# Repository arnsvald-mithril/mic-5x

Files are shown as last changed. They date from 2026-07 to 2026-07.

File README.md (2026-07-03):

# MIC-5X — Indoor Microclimate Monitor

**MITHRIL ELECTRONICS** · Doc. MTH-DS-0001 · Datasheet Rev. C.1

A 5-parameter indoor microclimate monitor built on a bare ESP8266 (ESP-12F)
module with a custom-designed analog dust-sensing front-end — not a
pre-built sensor module, but a discrete nephelometric channel (IR LED +
photodiode + LM358 transimpedance amplifier) designed, simulated, and
laid out from scratch.

Board render
*(replace with actual board photo/render)*

## Measured parameters

| Parameter | Sensor  | Interface |
|---|---|---|
| Temperature | DHT22 | Digital (1-Wire-like) |
| Relative humidity | DHT22 | Digital |
| Barometric pressure | BMP280  | I2C |
| Illuminance | BH1750  | I2C |
| Particulate matter (dust) | Custom analog nephelometric channel | ADC (ESP8266 TOUT) |

Full electrical characteristics, error budget, and mechanical drawings:
see `datasheet/MIC-5X_Datasheet_RevC1.pdf`.

## Engineering highlights

- **Analog front-end design.** Custom TIA stage (LM358) for the dust
  channel, simulated in LTspice: DC transfer characteristic
  0.3-3.3 V at 0-30 uA photocurrent, two-pole filter (tau ~= 1.8 ms,
  -3 dB at ~90 Hz). See `hardware/simulation/`.
- **Full error budget.** Aggregated RSS error ~5-7%, dominated by LED
  thermal drift (~4-6%), with contributions from Vref/AMS1117 (~1.5%),
  R3 tempco (~0.3%), and LM358 bias current (~0.5%).
- **Bare-module hardware design.** Migrated from a NodeMCU dev board
  to a bare ESP-12F module with full boot-strapping (EN/RST/GPIO0/GPIO2
  pull-ups, GPIO15 pull-down), a complete power protection chain
  (PolyFuse -> Schottky -> TVS -> AMS1117), and ADC input protection
  for the dust channel.
- **DRC-clean 2-layer PCB** in KiCad, including ground pour with
  stitching vias.
- **Non-blocking firmware.** ~300-line Arduino sketch using millis()
  scheduling (no delay()), with sensor cross-validation (DHT22 vs
  BMP280 temperature check), pressure trend detection, and a fallback
  AP mode for field configuration.
- **3D-printed enclosure**, parametrically modeled in CadQuery, with
  snap-fit assembly (no screws) and a dedicated cross-flow air path
  for the dust sensor.

## Repository structure

```
mic-5x/
    hardware/
        schematic/     KiCad schematic + PDF export
        pcb/            KiCad PCB layout
        simulation/     LTspice results (TIA transfer & frequency response)
    firmware/           ESP8266 Arduino firmware
    enclosure/           CadQuery enclosure script + STEP/STL exports
    datasheet/           Full Rev. C.1 datasheet (PDF)
    docs/images/         Board photos, renders, simulation plots
```

## Known limitations

This is an honest engineering datasheet, not a marketing sheet —
current known issues:

- Dust channel is **not yet calibrated on real aerosol**; the
  0.3-3.3 V range is the simulated full-scale transfer characteristic,
  not a validated ppm/ug*m^-3 curve.
- Enclosure snap-fit tongues are sized for **PLA** specifically
  (~0.9% strain after redesign); other materials would need
  re-verification of engagement geometry.
- LTspice .asc source files were iterated in a single working draft
  and not preserved as separate versions — simulation plots are
  archived in docs/images/, and the circuit is fully reproducible
  from the parameters listed in the datasheet.
- Enclosure errata (S6.6 of the datasheet) documents six issues found
  during design review and their fixes (exhaust port, fan bore
  clearance, snap-fit strain, screw sizing, stray light path).

## License

MIT — see LICENSE.

## Author

Oleksandr Didyk — Bachelor of Electronics, Igor Sikorsky Kyiv
Polytechnic Institute, Faculty of Electronics, specialization in
Electronic Devices and Systems.

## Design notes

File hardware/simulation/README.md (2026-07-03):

\# LTspice simulations

Two key simulations validate the analog dust-sensing front-end (TIA stage):

1. \*\*Transfer characteristic\*\* — DC sweep 0–30 µA photocurrent →

0\.3–3.3 V output. Confirms the TIA gain stage operating range

used in the error budget (see datasheet §5.4).

TIA transfer

1. \*\*Frequency response\*\* — two-pole filter, τ ≈ 1.8 ms,

−3 dB at ~90 Hz.

TIA frequency response

Original `.asc` files were iterated directly and not preserved as

separate versions. Circuit parameters (Rf, Cf, LM358 config, BPW34

model) are fully specified in the datasheet and can be rebuilt from

those values if needed.

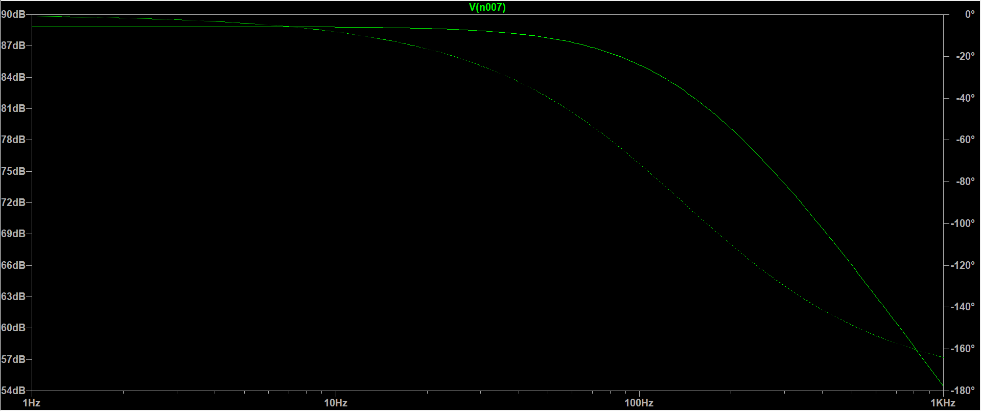
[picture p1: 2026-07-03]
docs/images/TIA_frequency_response.png

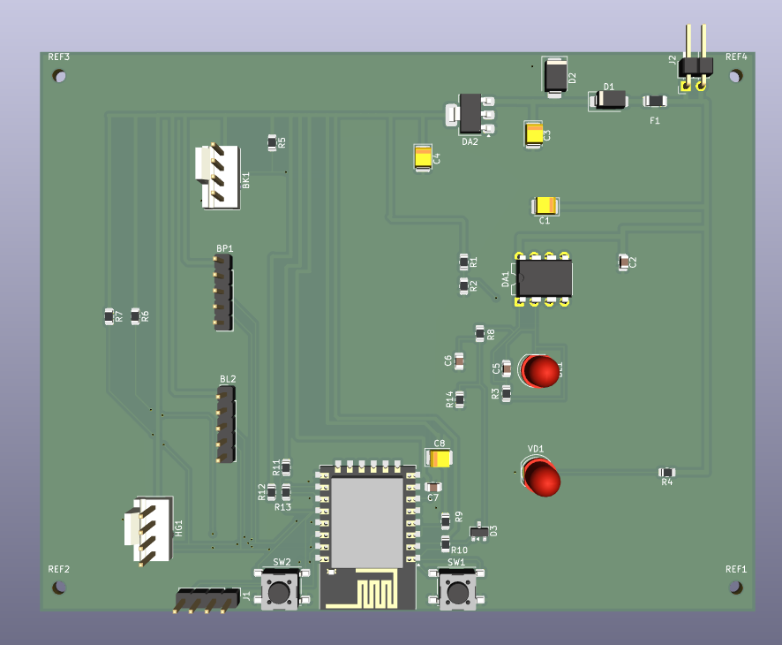
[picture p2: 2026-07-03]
docs/images/3D_model.png

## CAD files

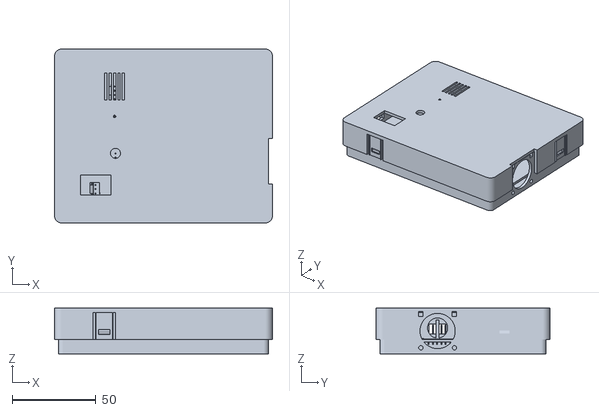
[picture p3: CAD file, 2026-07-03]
enclosure/exports/Assembly.stl
130.0 x 103.6 x 27.2

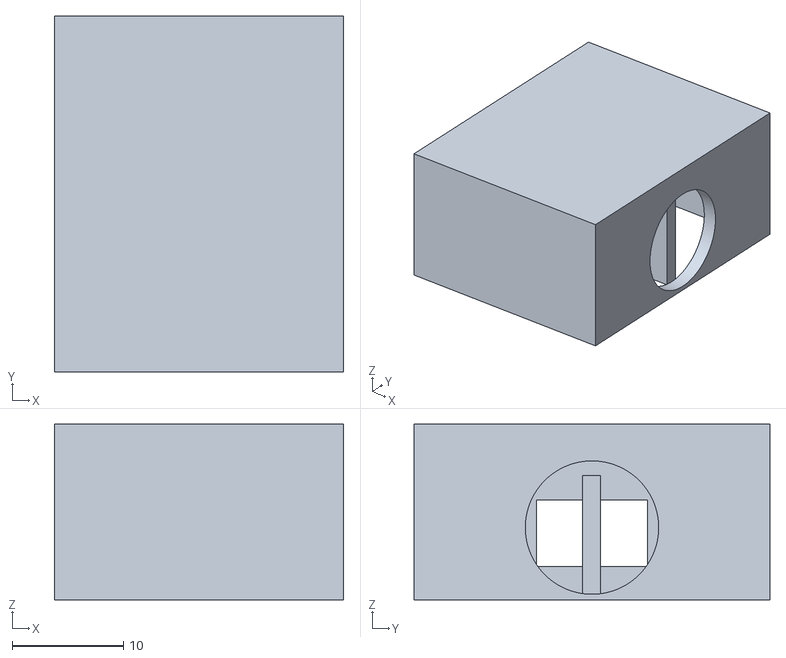
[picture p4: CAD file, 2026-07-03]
enclosure/exports/MIC5X_chamber_v8.stl
26.0 x 32.0 x 15.8

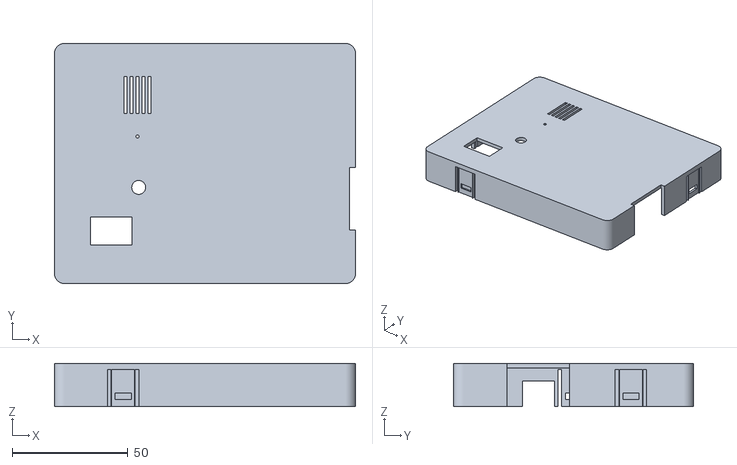
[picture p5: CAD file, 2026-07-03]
enclosure/exports/MIC5X_cover_v8(1).stl
130.0 x 103.6 x 18.7

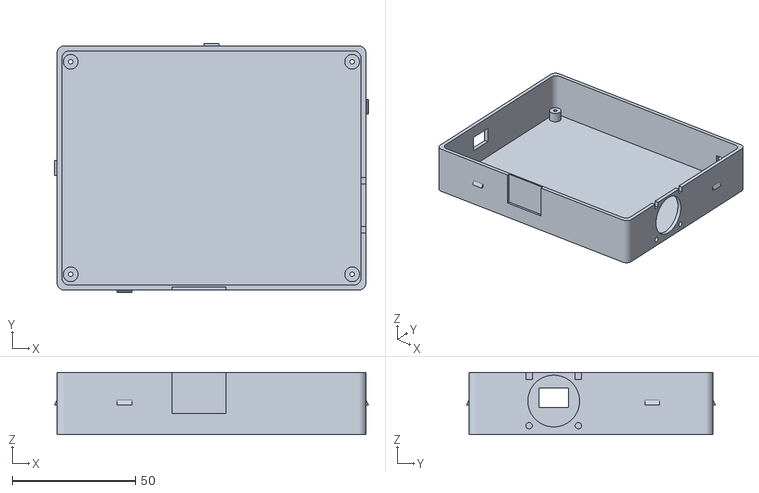
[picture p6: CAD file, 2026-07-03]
enclosure/exports/MIC5X_base_v8.stl
127.5 x 101.1 x 25.2

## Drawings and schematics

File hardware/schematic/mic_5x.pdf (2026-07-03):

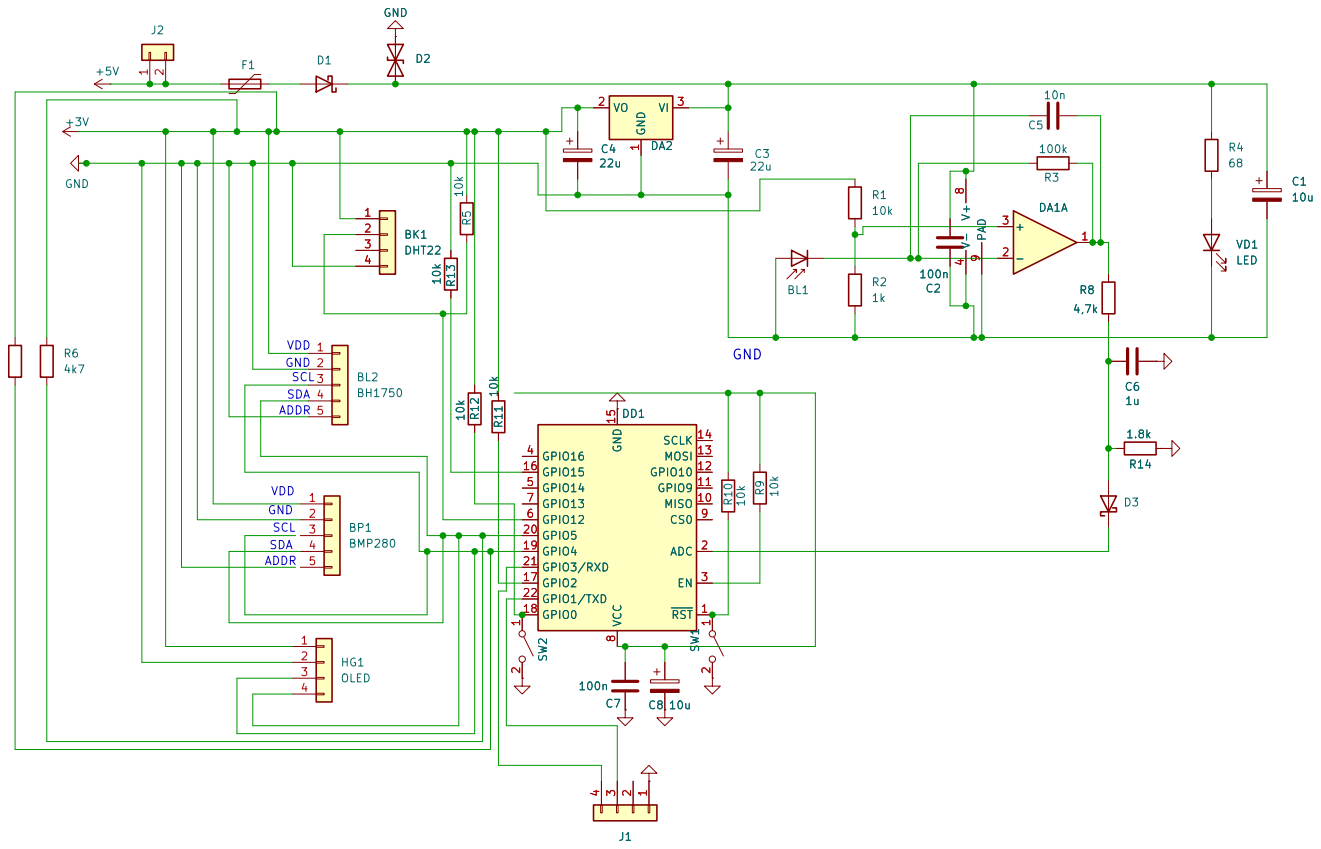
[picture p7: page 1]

Size: A4 | Rev:
KiCad E.D.A. 10.0.3 | Id: 1/1

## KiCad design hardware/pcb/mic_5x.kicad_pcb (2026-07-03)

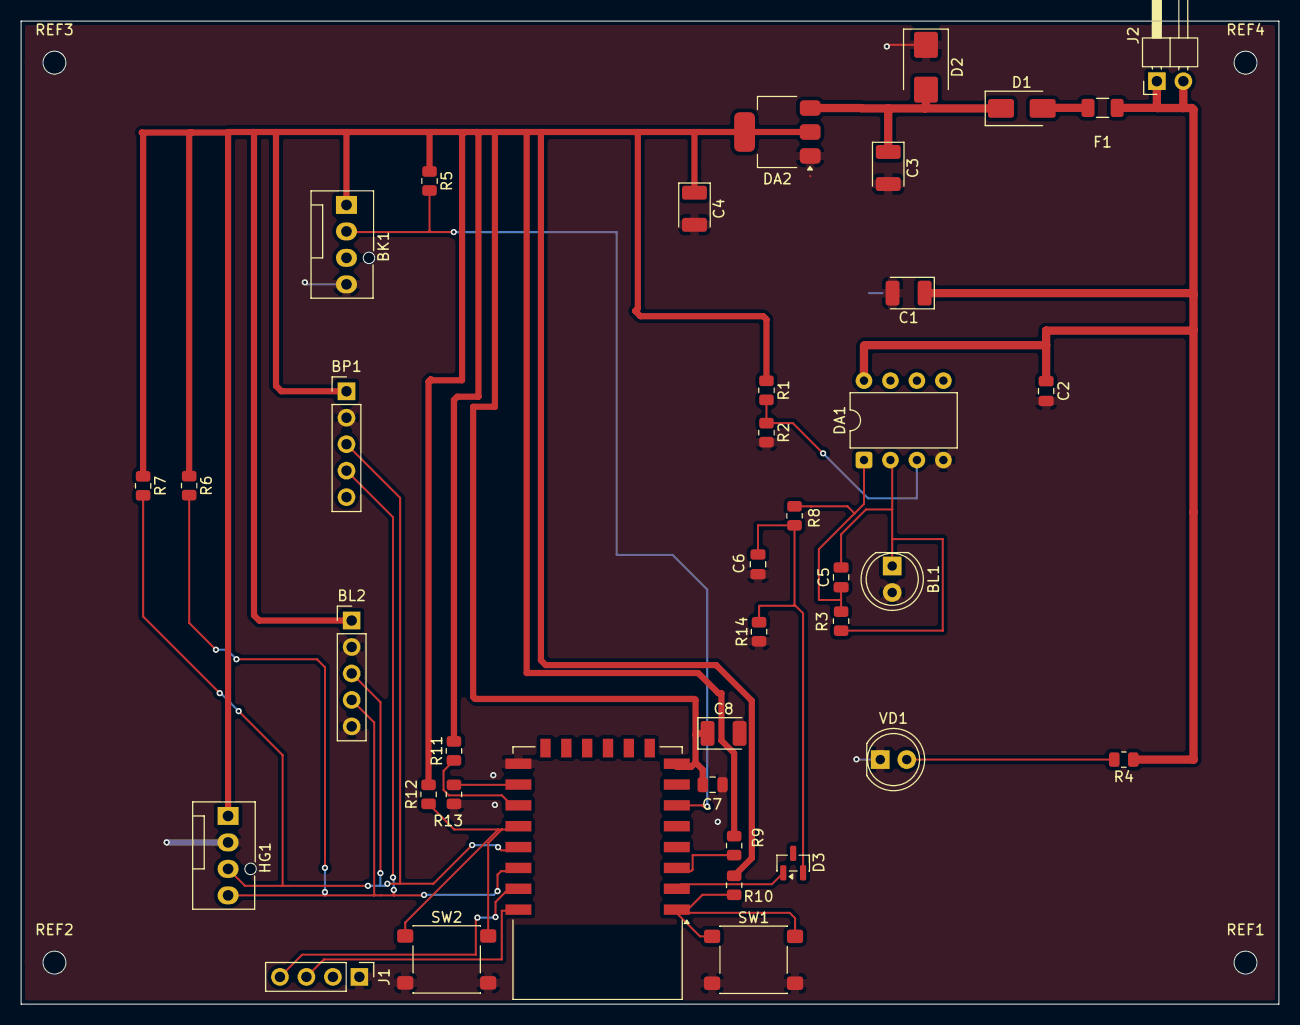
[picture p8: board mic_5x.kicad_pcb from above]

Board: 2 copper layers, 120.7 x 94.3 mm, 43 parts (0 on the bottom side), 21 nets.

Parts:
BK1: DHT22; FanPinHeader_1x04_P2.54mm_Vertical
BL1: D_Photo; LED_D5.0mm
BL2: BH1750; PinHeader_1x05_P2.54mm_Vertical
BP1: BMP280; PinHeader_1x05_P2.54mm_Vertical
C1, C8: 10u; CP_EIA-3528-21_Kemet-B
C2, C7: 100n; C_0805_2012Metric
C3, C4: 22u; CP_EIA-3528-21_Kemet-B
C5: 10n; C_0805_2012Metric
C6: 1u; C_0805_2012Metric
D1: D_Schottky; D_SMA
D2: D_TVS; D_SMB
D3: D_Schottky; SOT-23
DA1: LM358_DFN; DIP-8_W7.62mm
DA2: AMS1117-3.3; SOT-223-3_TabPin2
DD1: ESP-12E
F1: Polyfuse; Fuse_1206_3216Metric
HG1: OLED; FanPinHeader_1x04_P2.54mm_Vertical
J1: Conn_01x04; PinHeader_1x04_P2.54mm_Vertical
J2: Conn_01x02; PinHeader_1x02_P2.54mm_Horizontal
R1, R5, R9, R10, R11, R12, R13: 10k; R_0805_2012Metric
R2: 1k; R_0805_2012Metric
R3: 100k; R_0805_2012Metric
R4: 68; R_0805_2012Metric
R6, R7: 4k7; R_0805_2012Metric
R8: 4,7k; R_0805_2012Metric
R14: 1.8k; R_0805_2012Metric
REF1, REF2, REF3, REF4: MountingHole_2.2mm_M2
SW1, SW2: SW_SPST; SW_SPST_PTS645Sx43SMTR92
VD1: LED; LED_D5.0mm

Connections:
+3V: BK1.1, BL2.1, BP1.1, C4.1, C7.1, C8.1, DA2.2 (VO), DD1.8 (VCC), HG1.1, R1.1, R5.1, R6.1, R7.1, R9.2, R10.2, R11.2, R12.2
+5V: C1.1, C2.1, DA1.8 (V+), F1.1, J2.1, J2.2, R4.1
GND: BK1.4, BL1.2 (A), BL2.2, BL2.5, BP1.2, C1.2, C2.2, C3.2, C4.2, C6.2, C7.2, C8.2, D2.1 (A1), DA1.4 (V-), DA2.1 (GND), DD1.15 (GND), HG1.2, J1.1, R2.2, R13.1, R14.1, SW1.2 (B), SW2.2 (B), VD1.1 (K)
unnamed: BK1.2, DD1.6 (GPIO12), R5.2
unnamed: BL1.1 (K), C5.2, DA1.2 (-), R3.2
unnamed: BL2.3, BP1.3, DD1.19 (GPIO4), HG1.3, R7.2
unnamed: BL2.4, BP1.4, DD1.20 (GPIO5), HG1.4, R6.2
unnamed: C5.1, DA1.1, R3.1, R8.1
unnamed: D1.2 (A), F1.2
unnamed: C3.1, D1.1 (K), D2.2 (A2), DA2.3 (VI)
unnamed: C6.1, D3.2 (A), R8.2, R14.2
unnamed: D3.1 (K), DD1.2 (ADC)
unnamed: DA1.3 (+), R1.2, R2.1
unnamed: DD1.3 (EN), R9.1
unnamed: DD1.18 (GPIO0), R12.1, SW2.1 (A)
unnamed: DD1.22 (GPIO1/TXD), J1.3
unnamed: DD1.17 (GPIO2), R11.1
unnamed: DD1.21 (GPIO3/RXD), J1.4
unnamed: DD1.16 (GPIO15), R13.2
unnamed: DD1.1 (~RST), R10.1, SW1.1 (A)
unnamed: R4.2, VD1.2 (A)

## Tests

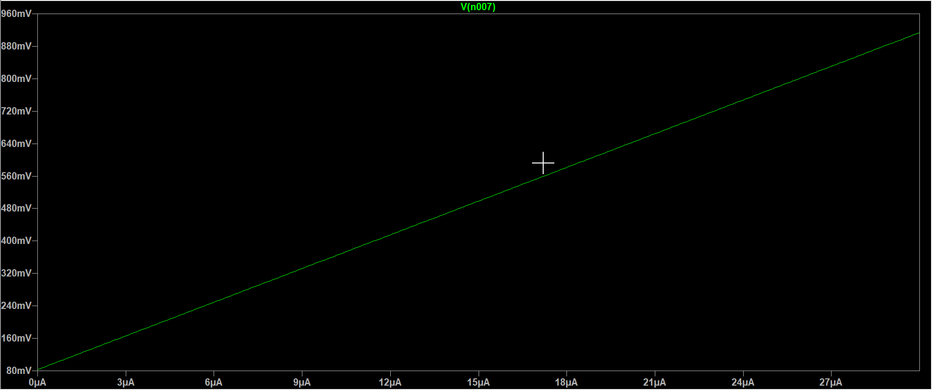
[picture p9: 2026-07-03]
docs/images/TIA_transfer_characteristic.png

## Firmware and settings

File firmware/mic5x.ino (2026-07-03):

/*
 * MIC-5X — 5-parameter indoor microclimate monitor
 * Firmware v1.1 (matches Datasheet Rev. C.1, §7 Firmware Summary)
 *
 * MCU:     ESP-12E / ESP-12F (ESP8266), bare module on custom 2-layer PCB
 * Sensors: DHT22 (T/RH), BMP280 (P/T, I2C), BH1750 (lux, I2C),
 *          custom nephelometric dust channel (TSAL6200 + BPW34 + LM358 TIA -> TOUT/A0)
 * Display: SSD1306 128x64 OLED (I2C)
 * Output:  HTTP server on port 80 ("/" HTML page, "/json" API)
 *
 * Design rules implemented (see datasheet):
 *  - Non-blocking loop: millis() scheduling, no delay() in steady state
 *  - DHT22 retried up to 3x, out-of-range readings rejected, last valid kept
 *  - Dust: burst of 16 ADC samples averaged (~x4 white-noise reduction);
 *    burst is taken OUTSIDE web-client handling to avoid the known ESP8266
 *    Wi-Fi-TX-vs-TOUT corruption
 *  - Temperature cross-check DHT22 vs BMP280 (warn if |dT| > 2 degC)
 *  - Pressure trend over ~30 min, threshold 0.3 hPa (rising/falling/stable)
 *  - Dust temperature compensation via BMP280 (linear tempco, §5.2)
 *
 * Libraries (Arduino IDE -> Library Manager):
 *  - Adafruit BMP280 Library (+ Adafruit Unified Sensor, Adafruit BusIO)
 *  - BH1750 (Christopher Laws)
 *  - DHT sensor library (Adafruit)
 *  - Adafruit SSD1306 + Adafruit GFX
 *
 * Board settings: "Generic ESP8266 Module", Flash 4MB, CPU 80 MHz.
 */

#include <ESP8266WiFi.h>
#include <ESP8266WebServer.h>
#include <Wire.h>
#include <Adafruit_BMP280.h>
#include <BH1750.h>
#include <DHT.h>
#include <Adafruit_GFX.h>
#include <Adafruit_SSD1306.h>

/* ============================ CONFIG ================================== */
/* !! Pin map: verify against the KiCad netlist of your PCB revision.
 * The values below are the conventional ESP-12E assignment used during
 * bring-up; the datasheet (Rev. C.1) does not pin these down.            */
#define PIN_I2C_SDA     4      // GPIO4  — SDA (BMP280, BH1750, SSD1306)
#define PIN_I2C_SCL     5      // GPIO5  — SCL
#define PIN_DHT         14     // GPIO14 — DHT22 single-wire data
#define PIN_DUST_ADC    A0     // TOUT via R8/R14 divider (~1 V full scale)

const char* WIFI_SSID   = "YOUR_SSID";
const char* WIFI_PASS   = "YOUR_PASSWORD";
const char* AP_SSID     = "MIC-5X";        // fallback AP if STA join fails
const char* AP_PASS     = "mic5xsetup";

const uint32_t SENSOR_PERIOD_MS   = 30000; // poll cycle (datasheet: 30 s)
const uint32_t WIFI_JOIN_TIMEOUT  = 20000;

/* Dust channel calibration (§5.1–5.2 of the datasheet).
 * V_clean: TIA output with clean air (dark/offset + stray light), mV at TOUT.
 * K_MV_PER_UGM3: slope from two-point calibration vs reference instrument.
 * DUST_TEMPCO: fractional signal drift per degC, compensated via BMP280 T.
 * Defaults are placeholders — MUST be calibrated per unit (§8).           */
float V_CLEAN_MV      = 90.0f;
float K_MV_PER_UGM3   = 0.45f;
float DUST_TEMPCO     = 0.004f;   // 0.4 %/degC, referenced to +25 degC

const float ADC_FULL_SCALE_MV = 1000.0f;  // ESP8266 TOUT ~0..1 V
const int   DUST_BURST_N      = 16;

/* ============================ GLOBALS ================================= */
ESP8266WebServer server(80);
Adafruit_BMP280  bmp;                       // I2C 0x76/0x77
BH1750           lux;                       // I2C 0x23
DHT              dht(PIN_DHT, DHT22);
Adafruit_SSD1306 oled(128, 64, &Wire, -1);  // I2C 0x3C

struct Readings {
  float tDht    = NAN;   // degC
  float rh      = NAN;   // %
  float tBmp    = NAN;   // degC
  float pHpa    = NAN;   // hPa
  float luxVal  = NAN;   // lx
  float dustMv  = NAN;   // raw averaged TOUT, mV
  float dustUg  = NAN;   // compensated estimate, ug/m3 (relative, §8)
  bool  tMismatch = false;
  char  pTrend  = 'S';   // 'R' rising / 'F' falling / 'S' stable
} rd;

uint32_t lastPoll = 0;
bool bmpOk = false, luxOk = false, oledOk = false;

/* Pressure trend: ring buffer of 1 sample/minute, compare now vs 30 min ago */
const uint8_t P_HIST_N = 30;
float    pHist[P_HIST_N];
uint8_t  pHistIdx = 0, pHistFill = 0;
uint32_t lastPHist = 0;
const float P_TREND_THRESHOLD = 0.3f;      // hPa (datasheet §7)

/* ============================ SENSORS ================================= */
bool readDHT() {
  for (uint8_t i = 0; i < 3; i++) {        // retry up to 3x (datasheet)
    float t = dht.readTemperature();
    float h = dht.readHumidity();
    // range validation; reject NaN and out-of-spec values
    if (!isnan(t) && !isnan(h) && t > -40 && t < 80 && h >= 0 && h <= 100) {
      rd.tDht = t; rd.rh = h;
      return true;                          // last valid retained otherwise
    }
    delay(50);                              // brief retry gap only on failure
  }
  return false;
}

void readBMP() {
  if (!bmpOk) return;
  rd.tBmp = bmp.readTemperature();
  rd.pHpa = bmp.readPressure() / 100.0f;
}

void readLux() {
  if (!luxOk) return;
  float v = lux.readLightLevel();
  if (v >= 0) rd.luxVal = v;
}

/* Dust: 16-sample burst on TOUT, averaged. Called from the sensor tick,
 * never from an HTTP handler, so it does not overlap Wi-Fi TX (§7 caveat). */
void readDust() {
  uint32_t acc = 0;
  for (int i = 0; i < DUST_BURST_N; i++) {
    acc += analogRead(PIN_DUST_ADC);        // 10-bit, 0..1023
    delayMicroseconds(300);                 // few-ms total burst
  }
  float raw = (float)acc / DUST_BURST_N;
  rd.dustMv = raw * ADC_FULL_SCALE_MV / 1023.0f;

  // Temperature compensation via BMP280 (§5.2), referenced to +25 degC
  float t = bmpOk && !isnan(rd.tBmp) ? rd.tBmp : 25.0f;
  float vComp = rd.dustMv / (1.0f + DUST_TEMPCO * (t - 25.0f));

  float ug = (vComp - V_CLEAN_MV) / K_MV_PER_UGM3;
  rd.dustUg = ug > 0 ? ug : 0;
}

void updatePressureTrend() {
  if (isnan(rd.pHpa)) return;
  if (millis() - lastPHist >= 60000UL || pHistFill == 0) {
    lastPHist = millis();
    pHist[pHistIdx] = rd.pHpa;
    pHistIdx = (pHistIdx + 1) % P_HIST_N;
    if (pHistFill < P_HIST_N) pHistFill++;
  }
  if (pHistFill < P_HIST_N) { rd.pTrend = 'S'; return; }
  float oldest = pHist[pHistIdx];           // ~30 min ago
  float d = rd.pHpa - oldest;
  rd.pTrend = (d >  P_TREND_THRESHOLD) ? 'R'
            : (d < -P_TREND_THRESHOLD) ? 'F' : 'S';
}

void pollSensors() {
  readDHT();
  readBMP();
  readLux();
  readDust();
  updatePressureTrend();
  // Redundancy cross-check (datasheet §7)
  rd.tMismatch = (!isnan(rd.tDht) && !isnan(rd.tBmp) &&
                  fabsf(rd.tDht - rd.tBmp) > 2.0f);
  updateOled();
}

/* ============================ OLED ==================================== */
void updateOled() {
  if (!oledOk) return;
  oled.clearDisplay();
  oled.setTextSize(1);
  oled.setTextColor(SSD1306_WHITE);
  oled.setCursor(0, 0);
  oled.printf("MIC-5X  %s\n", WiFi.isConnected()
              ? WiFi.localIP().toString().c_str() : "AP mode");
  oled.printf("T: %.1fC  RH: %.0f%%\n", rd.tDht, rd.rh);
  oled.printf("P: %.1f hPa %c\n", rd.pHpa,
              rd.pTrend == 'R' ? '^' : rd.pTrend == 'F' ? 'v' : '-');
  oled.printf("Lux: %.0f\n", rd.luxVal);
  oled.printf("Dust: %.0f ug/m3\n", rd.dustUg);
  if (rd.tMismatch) oled.print("! T sensors differ");
  oled.display();
}

/* ============================ WEB ===================================== */
const char* trendStr() {
  return rd.pTrend == 'R' ? "rising" : rd.pTrend == 'F' ? "falling" : "stable";
}

void handleRoot() {
  char buf[1200];
  snprintf(buf, sizeof(buf),
    "<!DOCTYPE html><html><head><meta charset='utf-8'>"
    "<meta http-equiv='refresh' content='30'>"          // auto-refresh 30 s
    "<meta name='viewport' content='width=device-width,initial-scale=1'>"
    "<title>MIC-5X</title><style>"
    "body{font-family:system-ui,sans-serif;background:#fff;color:#123;"
    "max-width:560px;margin:24px auto;padding:0 16px}"
    "h1{font-size:20px;border-bottom:2px solid #1b3a5c}"
    "table{width:100%%;border-collapse:collapse}"
    "td{padding:8px 6px;border-bottom:1px solid #dde}"
    "td:last-child{text-align:right;font-weight:600}"
    ".w{color:#b05a52}</style></head><body>"
    "<h1>MIC-5X &mdash; Indoor Microclimate</h1><table>"
    "<tr><td>Temperature (DHT22)</td><td>%.1f &deg;C</td></tr>"
    "<tr><td>Humidity</td><td>%.0f %%</td></tr>"
    "<tr><td>Temperature (BMP280)</td><td>%.1f &deg;C</td></tr>"
    "<tr><td>Pressure</td><td>%.1f hPa (%s)</td></tr>"
    "<tr><td>Illuminance</td><td>%.0f lx</td></tr>"
    "<tr><td>Dust (relative)</td><td>%.0f &micro;g/m&sup3;</td></tr>"
    "<tr><td>Dust raw</td><td>%.0f mV</td></tr></table>"
    "%s<p style='color:#789;font-size:12px'>Auto-refresh 30 s &middot; "
    "<a href='/json'>/json</a></p></body></html>",
    rd.tDht, rd.rh, rd.tBmp, rd.pHpa, trendStr(), rd.luxVal,
    rd.dustUg, rd.dustMv,
    rd.tMismatch ? "<p class='w'>Warning: DHT22/BMP280 differ &gt;2&deg;C</p>" : "");
  server.send(200, "text/html", buf);
}

void handleJson() {
  char buf[320];
  snprintf(buf, sizeof(buf),
    "{\"t_dht\":%.1f,\"rh\":%.0f,\"t_bmp\":%.1f,\"p_hpa\":%.1f,"
    "\"p_trend\":\"%s\",\"lux\":%.0f,\"dust_ugm3\":%.0f,"
    "\"dust_mv\":%.0f,\"t_mismatch\":%s,\"uptime_s\":%lu}",
    rd.tDht, rd.rh, rd.tBmp, rd.pHpa, trendStr(), rd.luxVal,
    rd.dustUg, rd.dustMv, rd.tMismatch ? "true" : "false",
    (unsigned long)(millis() / 1000));
  server.send(200, "application/json", buf);
}

/* ============================ SETUP/LOOP ============================== */
void setup() {
  Serial.begin(115200);
  Serial.println(F("\nMIC-5X fw v1.1"));

  Wire.begin(PIN_I2C_SDA, PIN_I2C_SCL);
  dht.begin();
  bmpOk  = bmp.begin(0x76) || bmp.begin(0x77);
  luxOk  = lux.begin(BH1750::CONTINUOUS_HIGH_RES_MODE);
  oledOk = oled.begin(SSD1306_SWITCHCAPVCC, 0x3C);
  Serial.printf("BMP280:%d BH1750:%d OLED:%d\n", bmpOk, luxOk, oledOk);

  if (bmpOk)
    bmp.setSampling(Adafruit_BMP280::MODE_NORMAL,
                    Adafruit_BMP280::SAMPLING_X2,   // temperature
                    Adafruit_BMP280::SAMPLING_X16,  // pressure
                    Adafruit_BMP280::FILTER_X16,
                    Adafruit_BMP280::STANDBY_MS_500);

  WiFi.mode(WIFI_STA);
  WiFi.begin(WIFI_SSID, WIFI_PASS);
  uint32_t t0 = millis();
  while (WiFi.status() != WL_CONNECTED && millis() - t0 < WIFI_JOIN_TIMEOUT)
    delay(250);
  if (WiFi.status() != WL_CONNECTED) {          // fallback AP for demo/setup
    WiFi.mode(WIFI_AP);
    WiFi.softAP(AP_SSID, AP_PASS);
    Serial.printf("AP mode: http://%s\n", WiFi.softAPIP().toString().c_str());
  } else {
    Serial.printf("STA: http://%s\n", WiFi.localIP().toString().c_str());
  }

  server.on("/", handleRoot);
  server.on("/json", handleJson);
  server.begin();

  pollSensors();                                // first reading immediately
  lastPoll = millis();
}

void loop() {
  server.handleClient();                        // stays responsive (no delay())
  if (millis() - lastPoll >= SENSOR_PERIOD_MS) {
    lastPoll = millis();
    pollSensors();                              // ADC burst outside HTTP handling
  }
}
